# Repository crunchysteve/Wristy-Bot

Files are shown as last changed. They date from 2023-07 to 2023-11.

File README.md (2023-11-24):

# Table of Contents
  * [Wristy-Bot](#wristy-bot)
  * [Workshop-Friendy Metal Mech](#Workshop-Friendy-Metal-Mech)
  * [Modular Design](#modular-design)
  * [Adaptable To Any Drum Kit](#adaptable-to-any-drum-kit)
  * [Housekeeping](#housekeeping)

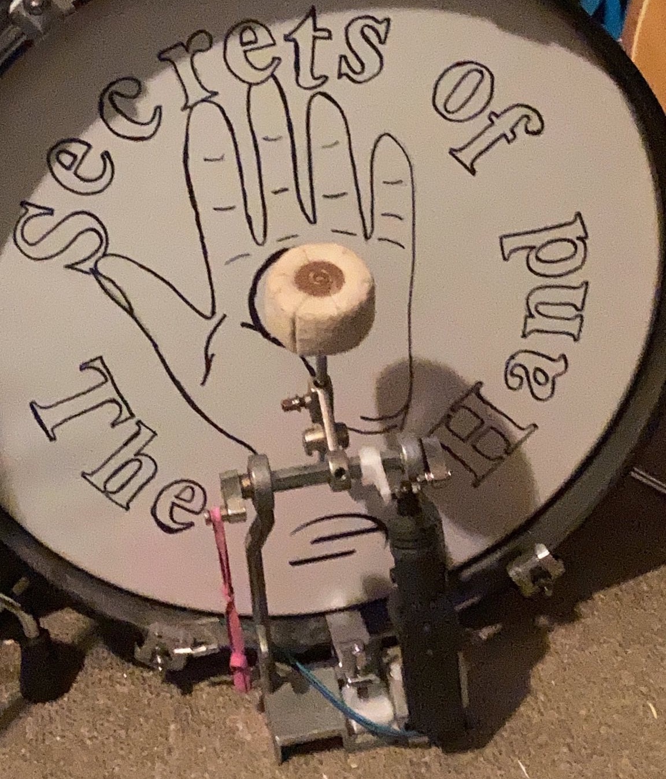
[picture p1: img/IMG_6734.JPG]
Kick-Bot mechanism mounted on a modified kick drum pedal attached to a 16" kick drum

# Wristy-Bot
Image: Kick-Bot mechanism mounted on a modified kick drum pedal attached to a 16" kick drum.
 
Arduino code and OpenSCAD drawings for a modular, adaptable robotic drum kit powered by MIDI input. There are three main principles to the project, the wrist-flick, modular design and adaptablity. This will allow almost any amount of drums in a kit, in almost any configuration, to be powered by any computer, sequencer or drum machine. Be it a rehearsal aid with a slightly more "human" feel, a major, distributed art installation or anything in between, Wristy-Bot will be adaptable to your needs.

Preliminary code and designs have been added and will be refined as I get time. CAD drawings are in OpenSCAD format. .scad files can be imported into FreeCAD and many other CAD programs if you need to work in a visual environment. The mechanical parts can be 3D printed, the electronics use a single arduino and a DC h-bridge to control a simple linear actuator.

All mechanisms, printed or metal, will use the same electronics, an arduino for reading MIDI and sending drive or park signals to the h-Bridge(s), and an h-bridge for each motor. As the Snare-Bot will use 2, or even 3, h-bridges and motors (same for hat-bot), you may want to use a Mega 2560 if you want to add a display and control panel for having control over settings or additional routines to generate advanced dynamics. Otherwise, a Nano or Uno will do the job. If you modify any of the designs or software, submit them as a pull request for review.

  * [To TOC](./)

## Workshop-Friendy Metal Mech

I've also added a design for an [all metal mechanism for StickBot](https://github.com/crunchysteve/Wristy-Bot/blob/main/Mechanisms/MetalHardware/README.md) and will be adding details of how to do KickBot and HatBot without 3D printing as well. I figure that not everybody has access to a 3D printer and, while the plastic prototype parts work very reliably, reducing our reliance on plastics is not a bad thing.

AluminiumDrumbot
Image: OpenSCAD render of all metal stick mech.

## Why "Wristy-Bot"?
Human drummers, well, good ones, at least, use a wrist-flick action, holding the stick near its balance point, cradling the back of the stick on their ring and pinky fingers. Propulsion by wrist flick stops just before the stick hits the skin, and the standard grip allows the stick to continue rotating until it hits the skin, where it rebounds and comes back to rest with the back of the stick on the minor fingers. While the CAD drawings with this repo show a much simpler mechanism than the human hand and wrist, the principle is the same - a sharp impulse force propells the tip of the stick towards the drum, but not driving the stick into the drum, instead allowing it to rotate beyond the actuator limit, then strike and rebound. The mechanism allows the "underbalanced" stick to repark itself by falling back to it's natural rest, with the help of the rebound as well as the balance of the stick.

  * [To TOC](./)

## Modular Design
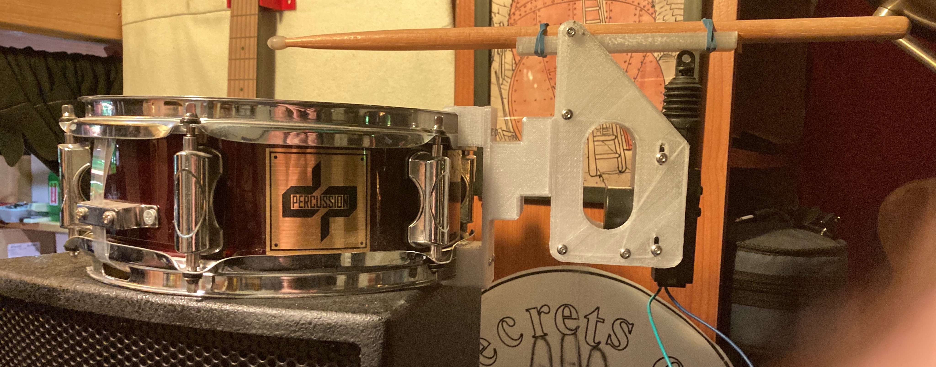
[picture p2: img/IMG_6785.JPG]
Stick-Bot mechanism mounted on a 10" wood snare.

Image: Stick-Bot mechanism mounted on a 10" wood snare.

The aim of this project is to create a public document that will help musicians with a modicum of microcontroller skills, or with a friend with said skills, to build a robotic drum kit, driven by a MIDI enabled drum machine or computer DAW (such as Logic Pro X or Ableton), such that one can practice while jamming to the more natural sound of real drums. The desire is to create an archive of firmware code and STL files for a set of 3D printable parts to mount the stick, beater and hi-hat mechanisms on mostly standard drum hardware. Each drum stick mech will be a standalone instrument, setup in firmware to read only the relevant MIDI codes for the drum it plays. All of the physical parts, such as the microcontroller, car door lock actuators and power control modules are readily available on eBay and Ali Express, and a recommended BOM will also be included with suggested search terms.

  * [To TOC](./)

## Adaptable To Any Drum Kit
The modular design, allowing the project to be built up and added to each drum or other drum kit parts, makes for adaptability to 4 piece, 5 piece or more, with each drumbot module being daisy-chaned via hardware MIDI thru, waiting for and responding only to its relevant MIDI codes - eg the snare waits for MIDI Snare 1 or Snare 2 and MIDI Sidestick commands, using Snare 1 for left stick and Snare 2 for right stick, with a third stick that can either be set up to strike a rim shot or a side stick, programmed in the drum machine to strike in unison with the left or right sticks. The kick drum will be setup to read Kick 1 as kick with rebound or Kick 2 as a damped kick, where the pedal is held against the skin to damp the beat. DOOF or duf, respectively. If you can imagine a way you'd like a drum kit played, you'll be able to adapt the code, designs and operation to suit the playing style. Imagine using a Logic Pro drummer track to play a real kit in the pocket of your recorded bass line.

  * [To TOC](./)

## Housekeeping
Of course, for any of this to be useful, it all needs to be understandable, simple, free and open source. If there's a commercial component to the music or art you make, that's fine, the art *created* by any user is not part of, nor affected by the licence. If you want to manufacture systems based on code, designs and parts, there is an additional, commercial clause added to the MIT licence. This doesn't exclude mass production, but it makes a strict requirement to negotiate a licence from project maintainer and payment to the project collective. This licence will apply to all forks.

Cheers,
Crunchy

  * [To TOC](./)

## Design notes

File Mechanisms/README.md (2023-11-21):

# Table of Contents
  * [Wristy-Bot Mechanisms](#wristy-bot-mechanisms)
  * [Workshop-Friendy Metal Hardware (to dedicated page)](./MetalHardware/README.md)
  * [Kick-Bot](#kick-bot)
  * [Stick-Bot](#stick-bot)
  * [Hat-Bot](#hat-bot)
  * [Electronics](#electronics)
    * [Arduino Or Others](#arduino-or-others)
    * [Motor Power Control](#motor-power-control)

# Wristy-Bot Mechanisms

There are 3 basic mechanisms, [Kick-Bot](./README.md), [SnareMount](./README.md) and Hat-Bot, the latter being still in development. The files kept here, in the appropriate folders are the OpenSCAD CAD files for use as is, or for importing into your CAD software of choice for parametric mods to suit your kit.

Much of the scope of this project is to use logic to ensure signals from the drum machine are played how a human would play the piece. For example, if a snare right and hi-hat right are called at the same time, the hi-hat beat will be diverted to the left stick on the hats, causing repeated left hits to maintain the beat. This is part of what will generate a "human" feel.

## Kick-Bot

Kick-Bot operates the kick drum beater and will respond to MIDI 35 and 36 in single kick mode, with 35 being a hit-and-rebound, 36 being a hit and hold. The hold will have a timeout so that the actuator and power control don't burnout. In double kick and two kicks mode, one beater will be driven by MIDI 35, the other by 36.

## Stick-Bot

Stick-Bot is the general workhorse of the system. More or less using the same hardware on drums, cymbals and other percussion as required. As part of the snare drum mechanism, it will be configurable with two sticks, using MIDI 38 and 40, and an option stick on the rim, using MIDI 37, "sidestick", in unison with MIDI 38 for a rimshot. This third stick will also be configurable as an actual sidestick sound on the side of the drum.

For other drums, it will be up to your needs to decide on double or single stick setups. Two stick-bots will also be needed for the hi-hat rig, also as a left and right stick, alternating based on the last stick that operated (left-right-left-right) and whether a snare hit was called (left or right), flicking the next due hit to the opposite.

## Hat-Bot

Hat-Bot will consist of 2 stick-bots and a hi-hat lifting mechanism, powered by a high torque digital servo motor. Hat-Bot is still under development.

## Electronics

### Arduino or Others

My plan is to use Arduino Nanos as the MIDI to mech translators, but I've also done test builds of the proof-of-concept firmware on a [Wio Terminal](https://wiki.seeedstudio.com/Wio-Terminal-Getting-Started/), which has a built in TFT screen and loads of GPIOs. It also runs a SAMD25 core, so its pretty fast with it. I'm building mine on a tight budget, so I'm using third party nanos at around AU$10 (US$7), but if you can spare 8* the figure per drum-bot module, go for it. Any micro will do the job.

### Motor Power Control.

I was planning to design and build my own H-Bridge, and the design works in simulation, but the mosfets alone were going to blow out to $30, and the idea of frying a few while solving some of the more practical construction problems felt a little uncomfortable. Luckily, there is the [BTS7960B high current H-Bridge](https://www.ebay.com/sch/i.html?_nkw=bts7960b&_fcid=15&_sop=15&_stpos=3204&_svsrch=1&rt=nc&LH_PrefLoc=98) and this baby is around 12 of my currency's bucks, delivered. It means a housing with 2 boards in it, but I can guarantee reliability with this board, and most come with the heatsink included.
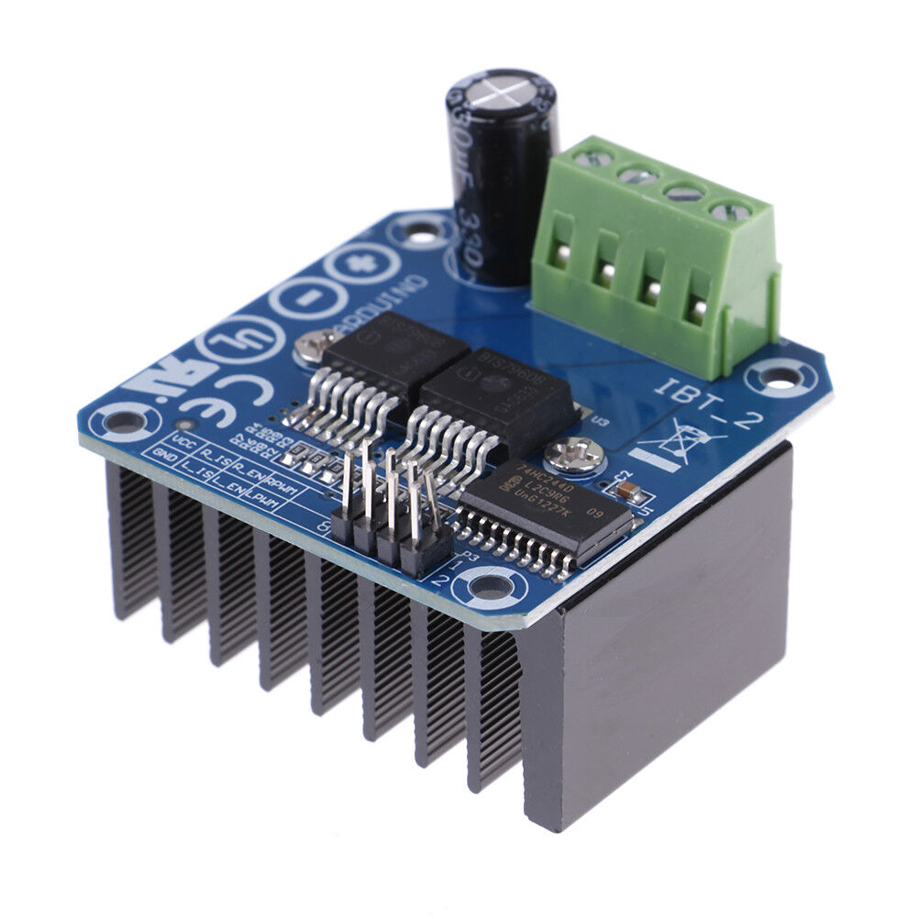
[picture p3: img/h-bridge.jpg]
A BTS7960B mosfet h-bridge, used for motor power control.


The purpose of the H-Bridge is to drive the actuators forwards (drive) on MIDI NoteOn and backwards (park) on MIDI NoteOff. The selected H-Bridge switches the supply through the motor bidirectionally and also varies the motor velocity using PWM with a duty cycle proportional to the MIDI velocity value, such that a MIDI velocity value of 1 provides the minimum drive to just touch the drum skin and a MIDI velocity value of 127 provides full voltage across the motor. MIDI Velocity 0 of course equals NoteOff.

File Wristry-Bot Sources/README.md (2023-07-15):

# Wristy-Bot Sources

These are stand-alone prototypes for a generalised controller module that will be configurable
To the desired drum and hardware.

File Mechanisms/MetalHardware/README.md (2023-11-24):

# Table of Contents
  * [Metal Hardware (Stick-Bot)](#METAL-HARDWARE-(Stick-Bot))
    * [Bill-of-Materials](#BILL-OF-MATERIALS)
    * [2D Sketch](#2D-SKETCH)
  * [Metal Hardware (Kick-Bot)](#METAL-HARDWARE-Kick-Bot)
  * [Metal Hardware (Hat-Bot)](#METAL-HARDWARE-Hat-Bot)

## METAL HARDWARE (Stick-Bot)
I'm kind of in the middle of a crisis of faith with 3D printing and have been adding more conventional tools to my workshop. This came about from trying out a resin printer, with "envornmentally friendly, plant based resin," only to discover the stuff is as toxic as any other, more conventional resin. The stink hung around for days. It made me look at my "skip of shame", a kids' toy box made to look like a mini skip ("dumpster" to North Americans) and, while it's not a lot of fails and sprues for 5 years of printing, it's still a lot of waste plastic that I'm still trying to find a use for. 

So, I thought I need to look into better ways to make this hardware, not just for cutting down my plastics generation, but for accessibility, as well. Plenty of people have basic tools in their workshop, 3D printers are a little less common. Sure, they're affordable, but musicians would rather spend money on instruments than tools, I'm sure. I just happen to have printing as an option. So here is a design for the drumBot mechanism that uses standard aluminium extrusions. This design also includes brackets to mount the stickbots to drums with t-nuts, wood screws or rivnuts in the sides of the drum. Don't build this onto your main kit, use a stunt kit, but hey, easier to make, easier to mount and slightly better for the planet.

AluminiumDrumbot

Version 1 of the all metal Kick-Bot is now described below and 2D sketches for it will be uploaded soon. HatBot is already mostly metal in construction and, if I design it to use standard v-slot extrusions, there are loads of standard brackets that can be pressed into service for mounting the lifter servo and the Stick Bots.

There are some parts and materials you'll need to buy for this basic Stick-Bot. I'll also upload some 2D drawings of each individual part, soon, and embed them here. These 2D plans will make it easier for those who don't read OpenSCAD, the CAD language I use to render my designs and create 3D printable models with. Stick bot 2D plans are already uploaded, Kick-Bot 2D drawings will be next.

All mechanisms, printed or metal, will use the same electronics, an arduino for reading MIDI and sending drive or park signals to the h-Bridge(s), and an h-bridge for each motor. As the Snare-Bot will use 2, or even 3, h-bridges and motors, you may want to use a Mega 2560 if you want to add a display and control panel for having control over settings or additional routines to generate advanced dynamics. Otherwise, a Nano or Uno will do the job. If you modify any of the designs or software, submit them as a pull request for review.

### BILL OF MATERIALS
``` Text
MATERIALS
(My materials are sourced from my local hardware and the actuators and bearings I sourced
from eBay, you may need to alter the design slightly. I also machined my own spacers and
threaded them for M3 screws.)

2x 1m lengths of 60x3 aluminium flatbar will build 10 (2x sides)
1x 1m length of 40x20x2   "     square tube will build 10 (rocker)
1x 1m length of 20mm      "     round bar (will build enough spacers)

      WORKING
        -   centre drill 3mm hole with lathe for all spacers
            cut 2 to 30mm lengths
            cut 2 to 4mm lengths after lathing outer to 5mm
      (...or use off the shelf spacers

1x 1m length of 40x12x1.6 aluminium angle will easily build brackets for 10 units.
1x car door linear actuator
2x MF83-2Z bearing 8mm OD x 3mm ID x 3mm Wide

Assorted M3 screws and nuts, including...
  M3x 40mm if spacers are unthreaded or M3x 8mm if the spacers are threaded.

Nuts, washers and other hardware as needed. I recommend nylok nuts and low dome head
allen screws.
```

### 2D SKETCH
Details to follow, but anybody competent in their workshop should be able to build these parts from standard extrusions (even imperial, just divide the mm by 25.4 for inches) and standard bolt, nut and spacer hardware. The 8mm hole through the stick cradle is to accomodate the 2 MF83-2Z 8x3x3 flanged bearings like this... 

MF83-2Z_bearing_8mmODx3mmIDx3mmW

These are readily available on eBay, Ali or that evil dog Jeff's store if you must give your money to that rich thief. This is [the bearing I used](https://www.ebay.com.au/itm/264688273390).

All other holes and slots are M3 (or 1/8 inch).
MetalDrumBot
Feel free to download these images or print this page.

## METAL HARDWARE (Kick-Bot)

An all metal version of Kick-Bot using a 120mm length of 50x50x3 aluminium tube and some lengths of 50x50x3 aluminium angle and 40x12x1.6 aluminium uneven angle. The drive is provided by an RS755 class 12v 4000rpm motor, coupled to a standard beater via a coupling made from a 20mm length of 20mm diameter aluminium solid bar. The shaft and beater holes are untapped, the smaller holes are threaded to provide clamping via M4 screws. 2D sketches coming soon.

|  Left, drum-side view  |  right, back-side view  |
|---|---|
|AllMetalKickDrumClampSideLeftSmall|AllMetalKickBotBackSideRightSmall|
| At the front, the 50x50 angle has its horizontal flange facing forwards, cut out in the middle and drilled in the middle of each remaining flange. On either side of this cutout are 2 pieces of 40x12 angle and a 12x12 wood block to support it. This part of the assemblu clampes to the kick drum rim. The electrical connection end of the motor can be seen protruding through the 44mm hole in the back of the beater riser. The motor direct drives the beater, via a cylindrical perpendicular coupling. M4 grub screws provide the locking force to keep the coupling on the motor shaft and the beater in the coupling. | The entire assembly is held together with M4 bolts of varying lengths. Use nylock nuts and loktite to ensure secure fastening. From this side you can clearly see the beater assembly on the motor shaft, the motor mounting screw holes and the hole ast the top of the beater riser for an M4x40 screw to hold the beater stop. The hole at the back is for a rubber foot similar to the rubber feet the the drum clamp bolts go through at the front. |

The motor chosen is a relatively standard, RS775, 12 volt, 4000 RPM, electric motor. These are often used in hand held vacuum cleaners, portable electric drills and other appliances, so should have plenty of torque for beating the kick drum. The Kick-Bot arduino will need a little extra code and circuitry to read the stall signal from the power control board, allowing for power cut on beat and park when the beater meets the drum sking or the backstop.

I'm using 50x50x3 metric aluminium tubing and angle for my base materials but, if you have a MIG, you could weld it up from steel rather than bolt it together. Even Aluminium can be MAPP gas "soldered", so that's also an option. The holes in the clamping jaws on the drum side of the assembly need to be larger than the M6 bolt and wing nut that tightens them against the kick drum rim, to allow for a range of tilt. Even an M10 hole with "mudguard" washers wouldn't be too big. I plan to cut these 40x12 angles from leftover 50x50x3 for added strength, but standard 40x40x1.6 might be OK.

## METAL HARDWARE (Hat-Bot)
(Coming Soon)

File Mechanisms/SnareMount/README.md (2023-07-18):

# Kick-Bot Mechanism

Stick-Bot mechanism mounted on a 10" wood snare
Image: Kick-Bot mechanism mounted on a 10" wood snare.

This assembly clamps onto the top and bottom rim of my piccolo snare. There's standoff between the clamp and the stick-bot stick and motor assembly. My plan is to generalise the designs to work on a number of sizes of drum. Another reason I use OpenSCAD, the ability to make a model parametric with standing variables in the first few lines of code that allow me to tweak the same part for different applications, just by changing a dimension.

The snare drum will be hit by two, alternating sticks, MIDI 38 being right stick and MIDI 40 for left. (Snare 1 and 2, respectively) The picture above shows one stick, the second mech will mou nt on the same side, with the pair of sticks fitting neatly between 2 tuners. The snare will later have a third stick mechanism added for MIDI 37, "sidestick" or "rimshot." By combining MIDI 37 and 38 in unison, a simulation of a "flatstick rimshot" can be created.

The 3D modelling files are as follows:-
- [KickActuatorPushrod.scad](./SnareMount.scad) The OpenSCAD 3D model of the snare drum clamp. (Importable to many other CAD programs.)
- [KickActuatorPushrod.stl](./SnareMount.stl) The slicer-ready mesh model for 3D printing.
- [KickActuatorMount.scad](./standoff.scad) The OpenSCAD 3D standoff bracket that spaces the stick tip over the drum centre. (Also importable to other CAD programs.)
- [KickActuatorMount.stl](./standoff.stl) The slicer-ready mesh model for 3D printing.

PLA will probably eventually weaken and fail. I'm using PETG as it's nearly as strong as, and less toxic than, ABS as well as slightly more elastic than PLA or ABS. It's also much easier to print on a basic machine than ABS. The SCAD model could also be used to machine a metal bracket out of aluminium channel or square hollow, either with hand tools or with a suitable CNC router.

I'm using this linear actuator...
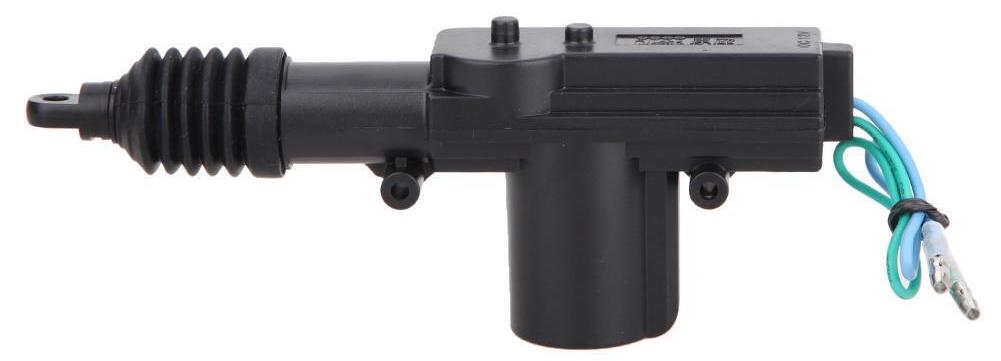
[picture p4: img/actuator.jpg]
door lock motor
[<br />links to eBay search](https://www.ebay.com/sch/i.html?_nkw=car+door+lock+actuator&_sacat=131090&_sop=15&_svsrch=1), add your country code to the domain where applicable.

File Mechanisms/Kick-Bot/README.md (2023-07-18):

# Kick-Bot Mechanism

Kick-Bot mechanism mounted on a modified kick drum pedal attached to a 16" kick drum
Image: Kick-Bot mechanism mounted on a modified kick drum pedal attached to a 16" kick drum.

I recommend using the riser frame of a "donor" kick pedal, removing the actual pedal and pull chain. What remains is the beater, hex axle, riser frame and drum clamp. To this, I've added a bracket to mount the linear actuator (a 12v, car door lock motor) and a push lever to fit onto the hex axle. 

While testing this by jabbing the leads onto a 12v SLA battery, I've come to the conclusion this probably needs 2 motors, brackets and pushrods to really bring the thump. This will probably also require 2 power control boards (see below) driven from the one output set, as the boards I've chosen for this job are 2 amp limit, as are the actuators.

The 3D modelling files are as follows:-
- [KickActuatorPushrod.scad](./KickActuatorPushrod.scad) The OpenSCAD 3D model pushrod on the hex axle. (Importable to many other CAD programs.)
- [KickActuatorPushrod.stl](./KickActuatorPushrod.stl) The slicer-ready mesh model for 3D printing.
- [KickActuatorMount.scad](./KickActuatorMount.scad) The OpenSCAD 3D model of the motor bracket. (Also importable to other CAD programs.)
- [KickActuatorMount.stl](./KickActuatorMount.stl) The slicer-ready mesh model for 3D printing.

PLA will probably eventually weaken and fail. I'm using PETG as it's nearly as strong as, and less toxic than, ABS as well as slightly more elastic than PLA or ABS. It's also much easier to print on a basic machine than ABS. The SCAD model could also be used to machine a metal bracket out of aluminium channel or square hollow, either with hand tools or with a suitable CNC router.

I used this linear actuator...
[door lock motor<br />links to eBay search](https://www.ebay.com.au/sch/i.html?_nkw=car+door+lock+actuator&_sacat=131090&_sop=15&_svsrch=1)

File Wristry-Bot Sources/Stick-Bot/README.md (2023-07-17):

# Stick-Bot Source Code
Source description for the basic principles of the general stick-bot code process.

```C++
//  stickbot.ino
//  Copyright ©2023 "Crunchysteve"
//  Stick-Bot prototype MIDI firmware
//  -----------------------------------------------------------------------------
//  Ready for alpha-testing, only, not yet built and uploaded. Use at own risk!
//  Kick-Bot is a relatively simple piece of code, but later might add support 
//  for switching between MIDI Kick1 as a beater hit-and-rebound with MIDI Kick2 
//  being hit-and-hold until MIDI NoteOff or dual beater/dual drum operation.

//  declare constants
#define MINVELO  64           // Map minimum velocity
#define MAXVELO 127           // Map maximum velocity
#define DRIVEPIN 10           // analogWrite() pin (drive)
#define PARKPIN 3             // tone() pin (parking)
#define PARKFRQ 250           // frequency to appear as DC to motor
#define SNARE1 38             // MIDI Snare1 - as the project generalises
#define SNARE2 40             // MIDI Snare2 - these will be in a header file
#define SIDE_STICK 37         // MIDI SideStick 
const uint32_t PARKTIME = 8;  // parking pulse width in milliseconds

//  declare global variables
int count = 0;                // LED_BUILTIN on/off state

//  Include libraries
#include <MIDI.h>             // Load MIDI class library

//  instantiate MIDI - Create MIDI port on Hardware Serial
MIDI_CREATE_DEFAULT_INSTANCE();

//  MIDI Callback Functions
//  -----------------------
//  Callback Functions handle MIDI commands

//  At some point, I want the drum-bot modules to flash an LED at tempo.
//  It's a quick diagnosting to check there are no firmware latencies.
void handleClock(){
  if(count >= 11){
    digitalWrite(LED_BUILTIN,
                !digitalRead(LED_BUILTIN));
            // Flash built in LED on half a beat, off half a beat
    count = 0;
            // reset counter
  } else {
    count++;
  }
}

// Function called when a NoteOn is received. MIDI NoteOn operates.
void handleNoteOn(byte channel,
                  byte pitch,
                  byte velocity){
  // Map MIDI velocities to practical mechanical velocities
  if(channel == 10){                      // check for drum notes
  int beater = map(velocity,1,127,MINVELO,MAXVELO);
    //  Only operate beater if kick drum MIDI noteOn recieved
    if(pitch == 35 || pitch == 36 && beater > MINVELO-1){
      noTone(PARKPIN);                    // interupt park
      delay(1);                           // elec safety delay
      analogWrite(DRIVEPIN, beater);      // drive at correct velocity
    }
  }
}

// Function called when a NoteOff is received. MIDI NoteOff parks the beater.
void handleNoteOff(byte channel, byte pitch, byte velocity){
  if(channel == 10){                      // check for drum note off
    //  Only park beater if kick drum MIDI NoteOff recieved.
    if(pitch == 35 || pitch == 36 && !velocity){
      analogWrite(DRIVEPIN,0);            // interrupt note
      delay(1);                           // elec safety delay
      tone(PARKPIN,
           PARKFRQ,
           PARKTIME); // park beater at 50% duty, approx 6 volts.
    }
  }
}

//  Arduino setup ruotine
void setup(){
    //  Set MIDI callbacks
    MIDI.setHandleClock(handleClock);
    MIDI.setHandleNoteOn(handleNoteOn);
    MIDI.setHandleNoteOff(handleNoteOff);
    // Initialise MIDI
    MIDI.begin(MIDI_CHANNEL_OMNI);
    //  At a later stage SoftwareSerial may be added to run MIDI
    //  leaving HardwareSerial free to provide debugging output.
    //  This is just a POC prototyp for Kick-Bot.
}

void loop(){
  // Sends MIDI commands to callback functions
  MIDI.read();
  //  Little else needs to be, nor should be done here,
  //  lest MIDI and mechanical responses are slowed.
  //  Some fast system checks may need to be run here in future
  //  but should be kept to minimal lines of code, and be 
  //  conditional on making a setting change (run or setup modes)
}
```

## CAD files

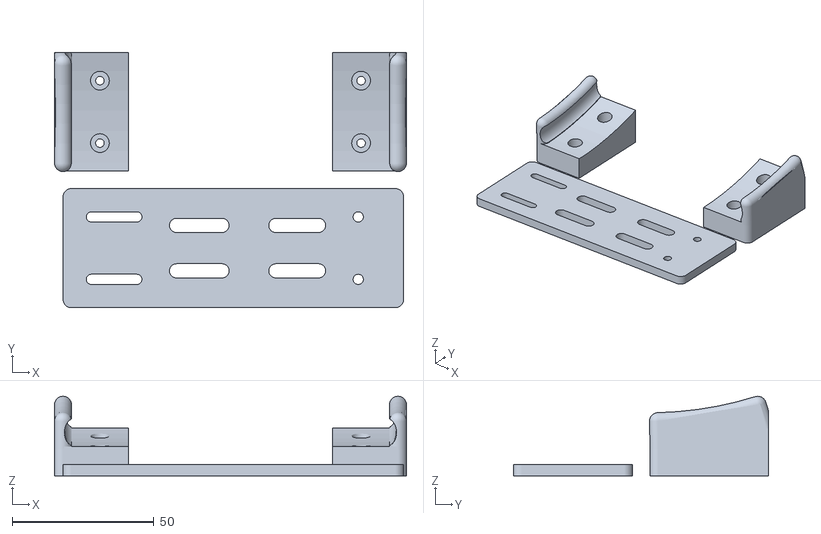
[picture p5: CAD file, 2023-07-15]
Mechanisms/SnareMount/SnareMount.stl
124.0 x 90.0 x 28.0

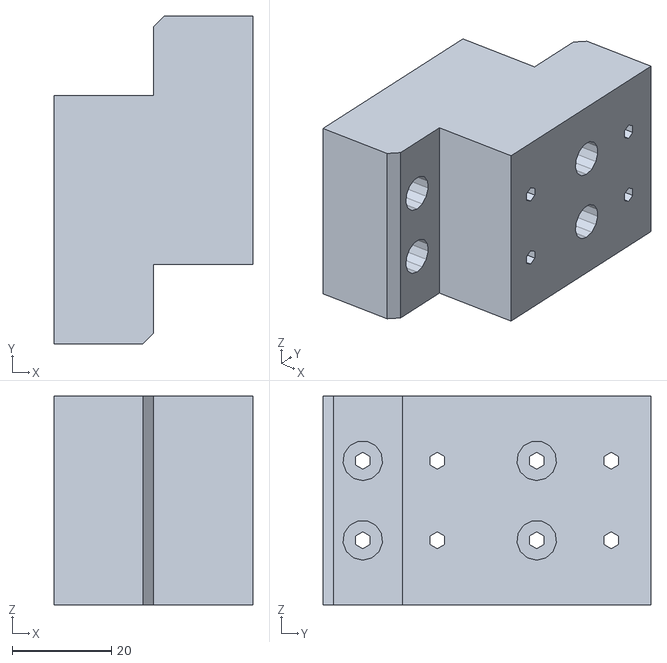
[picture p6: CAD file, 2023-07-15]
Mechanisms/SnareMount/standoff.stl
40.0 x 66.0 x 42.0

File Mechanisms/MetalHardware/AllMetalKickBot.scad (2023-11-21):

translate([-13.5,0,100]) rotate([26.7,0,0]) rotate([0,90,0]){
    beaterAdapter();
    translate([-160,0,14]) rotate([0,90,0]) beater();
}
translate([-88.5,0,100]) rotate([0,90,0]) motorType775();
beaterRiser();
beaterRest();
drumFoot();
backFoot();
translate([-100,28,3]) woodPad();
translate([40,28,3]) woodPad();
drumClamp();
mirror([1,0,0]) drumClamp();

color("silver") translate([-17,-25,3]) difference(){
    union(){
        cube([47,50,3]);
        translate([0,47,0]) cube([47,3,50]);
    }
    for(x=[10,37]) for(y=[10,37]){
        translate([x,y,-1]) cylinder(r=2,h=5);
    }
    for(x=[10,37]) for(z=[10,37]){
        translate([x,46,z]) rotate([-90,0,0]) cylinder(r=2,h=5);
    }
}

module drumClamp() color("silver") translate([40,28,15]){
    difference(){
        union(){
            cube([60,40,1.6]);
        translate([0,38.4,-10.4]) cube([60,1.6,12]);
        }
        translate([25,17,-1]) cylinder(r=3,h=5);
    }
}

module woodPad() color("wheat") cube([60,12,12]);

module backFoot() color("silver") translate([-20,-75,0]){
    difference(){
        union(){
            cube([3,100,50]);
            cube([50,100,3]);
        }
        for(y=[60,90]) for(z=[13,40]){
            translate([-1,y,z]) rotate([0,90,0]) cylinder(r=2,h=5);
        }
        translate([25,20,-1]) cylinder(r=3,h=5);
    }
}

module drumFoot() color("lightgray") translate([-100,25,0]){
    difference(){
        union(){
            cube([200,3,50]);
            cube([60,50,3]);
            translate([140,0,0]) cube([60,50,3]);
        }
        for(x=[40,70]) for(z=[10,40]){
            translate([x,4,z]) rotate([90,0,0]) cylinder(r=2,h=5);
        }
        for(x=[93,120]) for(z=[13,40]){
            translate([x,-1,z]) rotate([-90,0,0]) cylinder(r=2,h=5);
        }
        translate([35,20,-1]) cylinder(r=3,h=5);
        translate([165,20,-1]) cylinder(r=3,h=5);
    }
}

module beaterRest() color("gray"){
    translate([-21.5,-15,120]) rotate([0,90,0]) cylinder(r=2,h=40);
}

module beaterRiser() color("lightgray"){
    translate([-70,-25,0]) difference(){
        cube([50,50,130]);
        for(x=[10,40]) for(z=[10,40]){
            translate([x,51,z]) rotate([90,0,0]) cylinder(r=2,h=5);
        }
        for(y=[13,40]) for(z=[10,40]){
            translate([48,y,z]) rotate([0,90,0]) cylinder(r=2,h=6);
        }
        translate([1.5,1.5,-1]) cube([47,47,132]);
        translate([48,25,100]) rotate([0,90,0]) cylinder(r=9,h=10);
        translate([48,25,85.5]) rotate([0,90,0]) cylinder(r=2,h=10);
        translate([-1,25,100]) rotate([0,90,0]) cylinder(r=21,h=10);
        translate([48,25,114.5]) rotate([0,90,0]) cylinder(r=2,h=10);
        translate([48,10,120]) rotate([0,90,0]) cylinder(r=2,h=10);
    }
}

module beaterAdapter() color("silver") difference(){
    cylinder(r=10,h=20);
    translate([0,0,-1]) cylinder(r=2.5,h=22);
    translate([0,0,14]) rotate([0,90,0]) cylinder(r=2.75,h=22);
    translate([0,11,6]) rotate([90,0,0]) cylinder(r=2,h=22);
    translate([0,11,14]) rotate([90,0,0]) cylinder(r=2,h=22);
    rotate_extrude() translate([10,0]){
        rotate([0,0,45]) square(1.5,center=true);
    }
    translate([0,0,20]) rotate_extrude() translate([10,0]){
        rotate([0,0,45]) square(1.5,center=true);
    }
}

module beater(){
    color("gray") translate([0,0,-0.1]) cylinder(r=12,h=1);
    color("wheat") cylinder(r=25,h=32);
    color("gray") translate([0,0,31.1]) cylinder(r=12,h=1);
    color("lightgray") translate([0,0,-5]) cylinder(r=2.5,h=200);
}

module motorType775() color("silver") difference(){
    union(){
        cylinder(r=21,h=66);
        translate([0,0,-5]) cylinder(r=8.75,h=76);
        translate([0,0,-9.8]) cylinder(r=2.5,h=95);
        translate([0,0,24]) cylinder(r=22,h=36);
        translate([0,0,66]) hull(){
            rotate_extrude() translate([20,0]) circle(1);
        }
    }
    translate([-14.5,0,60]) cylinder(r=2,h=10);
    translate([14.5,0,60]) cylinder(r=2,h=10);
}

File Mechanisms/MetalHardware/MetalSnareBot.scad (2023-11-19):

// Aluminium Drum Robot Parts

translate([0,0,160]) rotate([0,10,0]) cradle();
translate([-10,18,0]) rotate([90,0,0]) side();
translate([-10,-15,0]) rotate([90,0,0]) side();
translate([0,0,10]) longSpacer();
translate([0,0,70]) longSpacer();
translate([0,0,160]) spacer();
translate([0,0,160]) mirror([0,1,0]) spacer();
translate([-5,0,0]) bracket();
translate([-15,0,0]) mirror([0,1,0]) bracket();

translate([50,0,-3.5]) mirror([1,0,0]) actuator(act=0);
translate([160,0,120.7]) rotate([0,-170,0]) stick();

/*
    MATERIALS
    2x 1m lengths of 60x3 aluminium flatbar will build 10 (2x sides)
    1x 1m length of 40x20x2   "     square tube will build 10 (rocker)
    1x 1m length of 10mm aluminium 
                    round bar (will build enough spacers)
            -   centre drill 3mm hole with lathe for all spacers
                cut 2 to 30mm lengths
                cut 2 to 4mm lengths after lathing outer to 5mm
    1x 1m length of 40x12x1.6 aluminium 
                angle will easily build brackets for 10 units.
    1x car door linear actuator
*/

module bracket() color("lightgray"){
    translate([-10,18,0]) difference(){
        union(){
            cube([40,1.6,80]);
            cube([1.6,12,80]);
        }
        hull(){
            translate([7,2,10]) rotate([90,0,0]) cylinder(r=2,h=4);
            translate([33,2,10]) rotate([90,0,0]) cylinder(r=2,h=4);
        }
        hull(){
            translate([7,2,70]) rotate([90,0,0]) cylinder(r=2,h=4);
            translate([33,2,70]) rotate([90,0,0]) cylinder(r=2,h=4);
        }
        translate([-1,7,10]) rotate([0,90,0]) cylinder(r=2.5,h=4);
        translate([-1,7,70]) rotate([0,90,0]) cylinder(r=2.5,h=4);
    }
}

module side() color("silver"){
    linear_extrude(height=3) difference(){
        offset(9.9) offset(-9.9){
            polygon([[0,0],[60,0],[60,100],[17,170],[0,170]]);
        }
        hull(){
            translate([10,10]) circle(2);
            translate([10,30]) circle(2);
        }
        hull(){
            translate([45,10]) circle(2);
            translate([45,30]) circle(2);
        }
        hull(){
            translate([45,68]) circle(2);
            translate([45,88]) circle(2);
        }
        hull(){
            translate([10,70]) circle(2.5);
            translate([10,90]) circle(2.5);
        }
        translate([10,160]) circle(2.5);
    }
}

module cradle() color("silver") difference(){
    translate([20,0,-5]) cube([80,20,30],center=true);
    translate([20,0,-0.5]) cube([82,16,36],center=true);
    translate([-41,-11,-4]) cube([31,22,37]);
    translate([10,-11,-4]) cube([51,22,37]);
    translate([0,11,0]) rotate([90,0,0]) cylinder(r=4,h=22);
    translate([-20,0,-4]) rotate([90,0,0]) 
            rotate([0,0,45]) cube([4,4,22],center=true);
    hull(){
        translate([-12,11,0]) rotate([90,0,0]) 
                rotate([0,0,45]) cylinder(r=2,h=22);
        translate([-12,11,-12]) rotate([90,0,0]) 
                rotate([0,0,45]) cylinder(r=2,h=22);
    }
    translate([-10,0,10]) rotate([90,0,0]) 
            rotate([0,0,45]) cube([4,4,22],center=true);
    translate([60,0,-4]) rotate([90,0,0]) 
            rotate([0,0,45]) cube([4,4,22],center=true);
    hull(){
        translate([45,11,0]) rotate([90,0,0]) 
                rotate([0,0,45]) cylinder(r=2,h=22);
        translate([45,11,-12]) rotate([90,0,0]) 
                rotate([0,0,45]) cylinder(r=2,h=22);
    }
    translate([10,0,10]) rotate([90,0,0]) 
            rotate([0,0,45]) cube([4,4,22],center=true);
}

module spacer() color("lightgray"){
    translate([0,15,0]) rotate([90,0,0]) difference(){
        cylinder(r=3,h=4);
        translate([0,0,-1]) cylinder(r=2.5,h=7);
    }
}

module longSpacer() color("lightgray"){
    translate([0,15,0]) rotate([90,0,0]) difference(){
        cylinder(r=5,h=30);
        translate([0,0,-1]) cylinder(r=1.3,h=33);
    }
}

module actuator(act=0) color("gray"){
    cylinder(r=11,h=98);
    cube([10,14,10],center=true);
    translate([0,0,act]) difference(){
        union(){
            cylinder(r=6,h=128);
            translate([0,0,128]) sphere(6);
        }
        translate([-7,2.5,122]) cube([14,7,26]);
        translate([0,10,128]) rotate([90,0,0]) cylinder(r=2.5,h=20);
        translate([-7,-9.5,122]) cube([14,7,26]);
    }
    translate([0,0,47]) rotate([0,90,0]) cylinder(r=14.5,h=44);
    translate([-12.5,-12.5,0]) cube([25,25,82]);
    difference(){
        translate([15.5,14.5,23]) 
                rotate([90,0,0]) cylinder(r=4,h=29);
        translate([15,14.5,23]) 
                rotate([90,0,0]) cylinder(r=1.8,h=30);
    }
    difference(){
        translate([15.5,14.5,81]) 
                rotate([90,0,0]) cylinder(r=4,h=29);
        translate([15,14.5,81]) 
                rotate([90,0,0]) cylinder(r=1.8,h=30);
    }
}

module stick(r=7.5,l=320) color("tan") translate([7.5,0,0]){
    sphere(r);
    rotate([0,90,0]) cylinder(r=r,h=l/2-2*r);
    translate([l/2-2*r,0,0]) 
            rotate([0,90,0]) cylinder(r1=r,r2=3*r/5,h=l/2);
    translate([l-10-2*r,0,0]) scale([7*r/18,1,1]) sphere(r);
}

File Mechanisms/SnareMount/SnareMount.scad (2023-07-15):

use<./standoff.scad>

//color("red") translate([64,0,0]) circle(90);

$fn=120;
translate([0,-3,42]) mirror([0,0,1]) 
        rotate([90,0,0]) brktHook();
translate([30,-3,0]) rotate([0,0,-90]) standoff();
translate([124,-3,42]) mirror([0,0,1]) 
        mirror([1,0,0]) rotate([90,0,0]) brktHook();

linear_extrude(height=4) translate([3,3]) difference(){
    offset(3) offset(-3) square([120,42]);
    translate([104,10]) circle(1.8);
    hull(){
        translate([10,10]) circle(1.8);
        translate([26,10]) circle(1.8);
    }
    hull(){
        translate([40,13]) circle(2.5);
        translate([56,13]) circle(2.5);
    }
    hull(){
        translate([40,29]) circle(2.5);
        translate([56,29]) circle(2.5);
    }
    hull(){
        translate([75,13]) circle(2.5);
        translate([90,13]) circle(2.5);
    }
    hull(){
        translate([75,29]) circle(2.5);
        translate([90,29]) circle(2.5);
    }
    hull(){
        translate([10,32]) circle(1.8);
        translate([26,32]) circle(1.8);
    }
    translate([104,32]) circle(1.8);
}

module brktHook() difference(){
    rotate([0,90,0]) translate([-147.2,0,0]) difference(){
        union(){
            linear_extrude(height=26) difference(){
                translate([127.2,3]) square([20,39]);
                circle(137);
            }
            translate([137,3.2,3]) 
                    rotate([0,90,0]) cylinder(r=3,h=10.2);
            translate([136.9,0.2,3]) cube([10.3,3,23]);
            translate([0,0,3]){
                difference(){
                    hull(){
                        translate([0,0,-3]){
                            linear_extrude(height=6) difference(){
                                translate([122,3]) square([20,36]);
                                circle(128);
                                translate([128,0,0]) 
                                        rotate([0,90,0]) 
                                                cylinder(r=3,h=12);
                            }
                        }
                        rotate([0,0,17.33]) translate([128,0,0]) 
                                rotate([0,90,0]) cylinder(r=3,h=12);
                    }
                    translate([0,0,-1]) cylinder(r=128,h=14);
                    translate([120,42,-6]) cube([40,10,14]);
                    translate([134,0,6]) sphere(3);
                }
                rotate([0,0,1.33]) translate([128,0,0]) 
                        rotate([0,90,0]) cylinder(r=3,h=12);
                rotate([0,0,1.33]) rotate_extrude(angle=16){
                    translate([128,0]) circle(3);
                }
                rotate([0,0,1.33]) translate([128,0]) sphere(3);
                rotate([0,0,17.33]) translate([128,0]) sphere(3);
            }
        }
        translate([0,0,7]) rotate_extrude(angle=19){
            translate([132,0]) scale([1.4,1]) circle(3.5);
        }
    }
    translate([16,10,-1]) cylinder(r=1.5,h=9);
    translate([16,10,3]) cylinder(r=3.3,h=9);
    translate([16,32,-1]) cylinder(r=1.5,h=9);
    translate([16,32,3]) cylinder(r=3.3,h=12);
}

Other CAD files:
Mechanisms/SnareMount/standoff.scad

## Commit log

2023-07-17 Upload files to 'Wristy-Bot-Designs'
    [KickActuatorMount.scad, KickActuatorMount.stl, KickActuatorPushrod.scad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]
2023-11-19 Create MetalSnareBot.scad
    Create folder and file.
    [MetalSnareBot.scad]
2023-11-19 Update MetalSnareBot.scad
    Add code
    [MetalSnareBot.scad]
2023-11-21 Add all metal Kick-Bot plans.
    [AllMetalKickBot.scad]
